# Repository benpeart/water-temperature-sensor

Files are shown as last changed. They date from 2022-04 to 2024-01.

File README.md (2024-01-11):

# IOT water temperature sensor

This is a relatively simple IOT sensor I put together to monitor the temperature of the water
coming from my outdoor wood boiler. The temperature probe monitors the temperature every 60
seconds and sends it to my Home Assistant server via ESPHome (or MQTT). I run ESPHome in a docker
on the same server running Home Assistant. See the enclosed docker-compose.yml.

## Home Assistant

Home Assistant has actions that notify me when the water exceeds 185 degrees and is at risk
of boiling over. This typically means I have left a door open and the fire is raging! I have
a second action when the water temperature goes under 145 which typically means I need to load
more firewood.

I found that the MAX31855 and K-Type temperature sensor resulted in noisy readings so have utilized
the median sliding window filter to filter out the outlier values. I observed very low readings for
periods up to 10 mintues. Since the temperature of the wood boiler doesn't change that quickly, I use
a fairly large window to ensure I remove the outliers and don't have false over/under temperature
notifications. My current settings are in esphome-wood-boiler.yaml. 

## Wiring Diagram

The wiring diagram is pretty simple. I found I had to use a 10k Ohm pull down resistor on the
Chip Select (CS) line or it wouldn't boot or flash reliably:

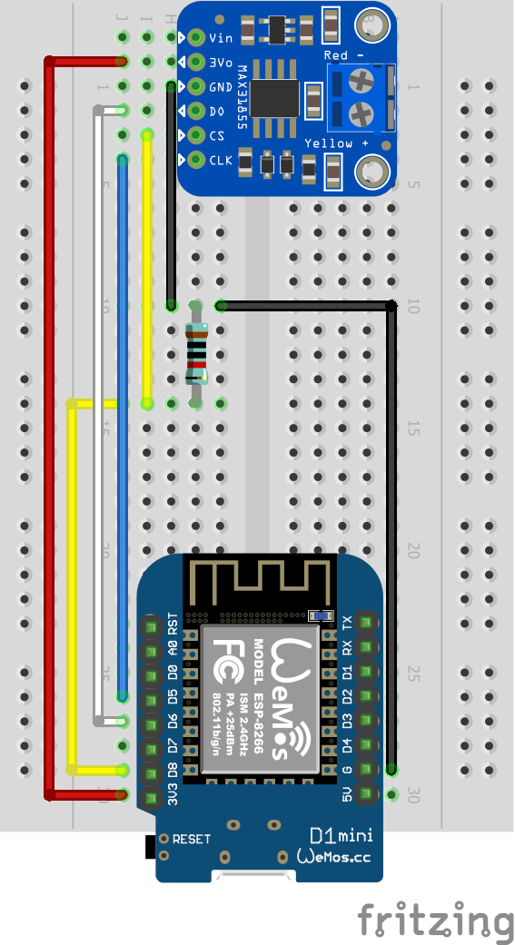
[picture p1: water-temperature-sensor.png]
Wiring Diagram


## 3D Printed Project Box

I also included the OpenSCAD file I used to 3D print a case to hold it all:

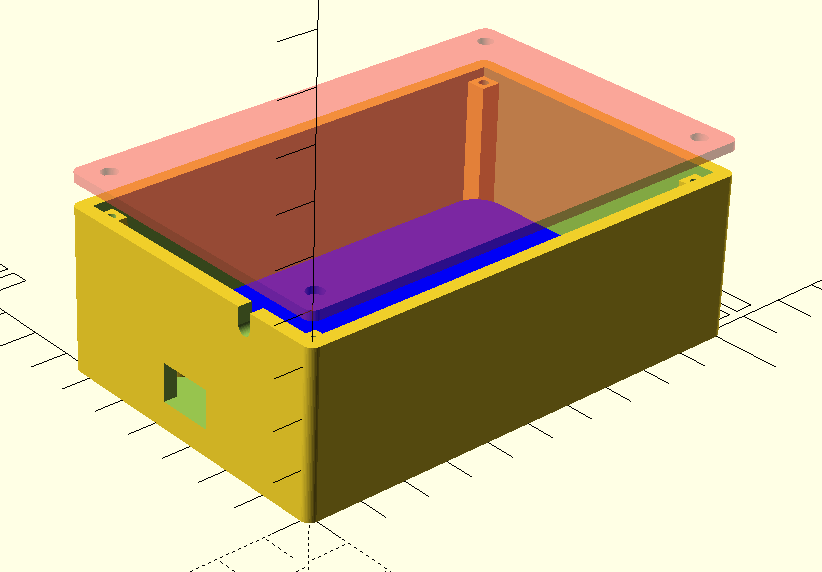
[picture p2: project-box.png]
Project Box


## Parts List

Here are the parts I used to build the solution:

[WeMos D1 Mini clone](https://smile.amazon.com/gp/product/B08C7FYM5T/ref=ppx_yo_dt_b_search_asin_title?ie=UTF8&psc=1)

[Adafruit MAX31855 breakout board](https://smile.amazon.com/gp/product/B00SK8NDAI/ref=ppx_yo_dt_b_search_asin_title?ie=UTF8&psc=1)

[ElectroCookie Solderable Breadboard](https://smile.amazon.com/gp/product/B07ZV8FWM4/ref=ppx_yo_dt_b_asin_title_o02_s01?ie=UTF8&psc=1)

[K-Type Pipe Thread Temperature Sensor Probe](https://smile.amazon.com/gp/product/B07QP6P3NL/ref=ppx_yo_dt_b_asin_title_o09_s00?ie=UTF8&psc=1)

[Stainless Steel Reducer](https://smile.amazon.com/gp/product/B07NZ9XQ19/ref=ppx_yo_dt_b_asin_title_o05_s00?ie=UTF8&psc=1)

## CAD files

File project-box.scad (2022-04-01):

$fn=50;

// ********************************************************************7
// Paremeters
// *********************************************************************

fudge=0.004;

// screw dimenstions
m2_screw_diameter = 2.2;
m3_screw_diameter = 3.2;
screw_length = 10;
screw_diameter = m2_screw_diameter;
screw_head_height = 1.5;
screw_head_diameter = 3.5;
screw_column_width = screw_diameter * 2;

// PCB dimensions
pcb_width = 88.9;
pcb_length = 52.1;
pcb_height = 1.6;
pcb_radius = 6;
mounting_hole_width = 78.7;
mounting_hole_length = 35.6;

// box interior dimensions
width = pcb_width + 2 * screw_column_width;
length = pcb_length + 2 * screw_column_width;
height = 30;

// case exterior dimensions
wall_thickness = 2;
wall_radius = wall_thickness;
case_width = width + 2 * wall_thickness;
case_length = length + 2 * wall_thickness;
case_height = height + 2 * wall_thickness;

// lid dimensions
lid_thickness = 4;
lid_clearance = 0.2;

// position of standoff for PCB
pcb_hole_x_offset = wall_thickness + (width - mounting_hole_width) / 2;
pcb_hole_y_offset = wall_thickness + (length - mounting_hole_length) / 2;
pcb_hole_diam = 2.2;
pcb_standoff_diameter = 5;
pcb_standoff_height = 5;

// sizes of penetrations
usb_width = 12;
usb_height = 8;
usb_height_from_pcb = 1;
thermocouple_diameter = 3;

// ********************************************************************7
// Build
// *********************************************************************

// Render the project box
project_box();

// You can render your pcb to show it inside the case
color("blue") translate([wall_thickness - wall_radius / 2 + screw_column_width + pcb_radius, wall_thickness - wall_radius / 2 + screw_column_width + pcb_radius,wall_thickness+pcb_standoff_height]) pcb();

// Render the lid
#translate([0,0,wall_thickness + height + lid_thickness / 2 + 5])
    project_lid();

// Render the lid for printing
*project_lid();

// ********************************************************************7
// Modules
// *********************************************************************

module project_box() 
{
    difference()
    {
        // make the outside box
        linear_extrude(case_height)
        {
            minkowski()
            {
                square([case_width - wall_radius, case_length - wall_radius]);
                circle(wall_radius);
            }
        }

        // remove the interior
        translate([wall_thickness - wall_radius / 2, wall_thickness - wall_radius / 2, wall_thickness])
            cube([width, length, height + wall_thickness + fudge]);

        // make a hole centered on the usb port above the PCB
        translate([- wall_radius - fudge, (case_length - wall_radius - usb_width) / 2, wall_thickness + pcb_standoff_height + pcb_height + usb_height_from_pcb - usb_height / 2]) 
            cube([wall_thickness + wall_radius / 2 + 2 * fudge, usb_width, usb_height]);
        
        // make a hole for the temperature probe
        translate([- wall_radius - fudge, case_length / 4 - wall_radius / 2, wall_thickness + case_height - lid_thickness - thermocouple_diameter / 2])
            rotate([0, 90, 0])
                union()
                {
                    cylinder(h = wall_thickness + wall_radius / 2 + fudge * 2, d = thermocouple_diameter);
                    translate([-lid_thickness, -thermocouple_diameter / 2, 0])
                        cube([lid_thickness, thermocouple_diameter, wall_thickness + wall_radius / 2 + fudge * 2]);
                }
    }

    // add columns to hold lid screws
    translate([wall_thickness - wall_radius / 2, wall_thickness - wall_radius / 2, wall_thickness])
        screw_column(screw_column_width, height, screw_diameter, screw_length);
    translate([width + wall_thickness - wall_radius / 2 - screw_column_width, wall_thickness - wall_radius / 2, wall_thickness])
        screw_column(screw_column_width, height, screw_diameter, screw_length);
    translate([wall_thickness - wall_radius / 2, length + wall_thickness - wall_radius / 2 - screw_column_width, wall_thickness])
        screw_column(screw_column_width, height, screw_diameter, screw_length);
    translate([width + wall_thickness - wall_radius / 2 - screw_column_width, length + wall_thickness - wall_radius / 2 - screw_column_width, wall_thickness])
        screw_column(screw_column_width, height, screw_diameter, screw_length);

    // add standoff for PCB
    translate([pcb_hole_x_offset - wall_radius / 2, pcb_hole_y_offset - wall_radius / 2, wall_thickness])
        round_stand_off(pcb_standoff_diameter, pcb_standoff_height, screw_length, screw_diameter);
    translate([pcb_hole_x_offset - wall_radius / 2 + mounting_hole_width, pcb_hole_y_offset - wall_radius / 2, wall_thickness])
        round_stand_off(pcb_standoff_diameter, pcb_standoff_height, screw_length, screw_diameter);
    translate([pcb_hole_x_offset - wall_radius / 2, pcb_hole_y_offset - wall_radius / 2 + mounting_hole_length, wall_thickness])
        round_stand_off(pcb_standoff_diameter, pcb_standoff_height, screw_length, screw_diameter);
    translate([pcb_hole_x_offset - wall_radius / 2 + mounting_hole_width, pcb_hole_y_offset - wall_radius / 2 + mounting_hole_length, wall_thickness])
        round_stand_off(pcb_standoff_diameter, pcb_standoff_height, screw_length, screw_diameter);
}

module project_lid()
{
    difference()
    {
        union()
        {
            linear_extrude(lid_thickness / 2)
            {
                minkowski()
                {
                    square([case_width - wall_radius, case_length - wall_radius]);
                    circle(wall_radius);
                }
            }
            translate([wall_thickness - wall_radius / 2, wall_thickness - wall_radius / 2, -lid_thickness / 2 + lid_clearance])
                cube([width, length, lid_thickness / 2 - lid_clearance]);
        }
        
        // TODO: mounting screw holes
        translate([screw_column_width / 2 + wall_thickness - wall_radius / 2, screw_column_width / 2 + wall_thickness - wall_radius / 2, - lid_thickness / 2 + lid_clearance / 2 - fudge])
            cylinder(h = lid_thickness + fudge * 2, d = screw_diameter);
        translate([-screw_column_width / 2 + wall_thickness - wall_radius / 2 + width, screw_column_width / 2 + wall_thickness - wall_radius / 2, - lid_thickness / 2 + lid_clearance / 2 - fudge])
            cylinder(h = lid_thickness + fudge * 2, d = screw_diameter);
        translate([screw_column_width / 2 + wall_thickness - wall_radius / 2, length - screw_column_width / 2 + wall_thickness - wall_radius / 2, - lid_thickness / 2 + lid_clearance / 2 - fudge])
            cylinder(h = lid_thickness + fudge * 2, d = screw_diameter);
        translate([-screw_column_width / 2 + wall_thickness - wall_radius / 2 + width, length - screw_column_width / 2 + wall_thickness - wall_radius / 2, - lid_thickness / 2 + lid_clearance / 2 - fudge])
            cylinder(h = lid_thickness + fudge * 2, d = screw_diameter);

        // TODO: mounting screw hole counter sinks
        translate([screw_column_width / 2 + wall_thickness - wall_radius / 2, screw_column_width / 2 + wall_thickness - wall_radius / 2, lid_thickness / 2 - screw_head_height + fudge])
            cylinder(h = screw_head_height + fudge, d = screw_head_diameter);
        translate([-screw_column_width / 2 + wall_thickness - wall_radius / 2 + width, screw_column_width / 2 + wall_thickness - wall_radius / 2, lid_thickness / 2 - screw_head_height + fudge])
            cylinder(h = screw_head_height + fudge * 2, d = screw_head_diameter);
        translate([screw_column_width / 2 + wall_thickness - wall_radius / 2, length - screw_column_width / 2 + wall_thickness - wall_radius / 2, lid_thickness / 2 - screw_head_height + fudge])
            cylinder(h = screw_head_height + fudge * 2, d = screw_head_diameter);
        translate([-screw_column_width / 2 + wall_thickness - wall_radius / 2 + width, length - screw_column_width / 2 + wall_thickness - wall_radius / 2, lid_thickness / 2 - screw_head_height + fudge])
            cylinder(h = screw_head_height + fudge * 2, d = screw_head_diameter);
    }
}

module pcb()
{
    linear_extrude(pcb_height) 
    {
        minkowski()
        {
            square([pcb_width - 2 * pcb_radius, pcb_length - 2 * pcb_radius]);
            circle(pcb_radius);
        }
    }
}


module screw_column(width, height, screw_diameter, screw_length)
{
    difference()
    {
        cube([width, width, height]);
        translate([width / 2, width / 2, height - screw_length])
            cylinder(h = screw_length + fudge, d = screw_diameter);
    }
}

module round_stand_off(diam, height, screw_length, screw_diam)
{
	difference()
	{
		translate([0,0,height/2])
            cylinder(h=height,r=diam/2, center=true);
		translate([0,0,height-screw_length])
            cylinder(h=screw_length+fudge,r=screw_diam/2);
	}
}
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

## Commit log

2022-04-01 Add documentation and source for the IOT water temperature sensor project.
    [project-box.scad, water-temperature-sensor.fzz]
2022-04-02 correct error in wiring diagram
    [water-temperature-sensor.fzz]
2022-12-24 The sensor is noisy and I get random low temperatures that I've been trying to filter out using Home Assistant. Add a sencor filter to remove outliers from the received sensor data.
    Pick some better defaults for the device.
2024-01-11 Update the noisy data filter to use a larger window to eliminate lingering random very low temperature readings that triggered false alerts.
